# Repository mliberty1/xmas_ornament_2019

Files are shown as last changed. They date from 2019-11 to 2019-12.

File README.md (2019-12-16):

# Introduction

This repository contains the hardware and software for the ornament designed
for Christmas 2019.  The ornament contains LEDs that illuminate through the
circuit board.  The LEDs are controlled by a SAMD21 processor running Arduino
code.  The ornament looks like this:

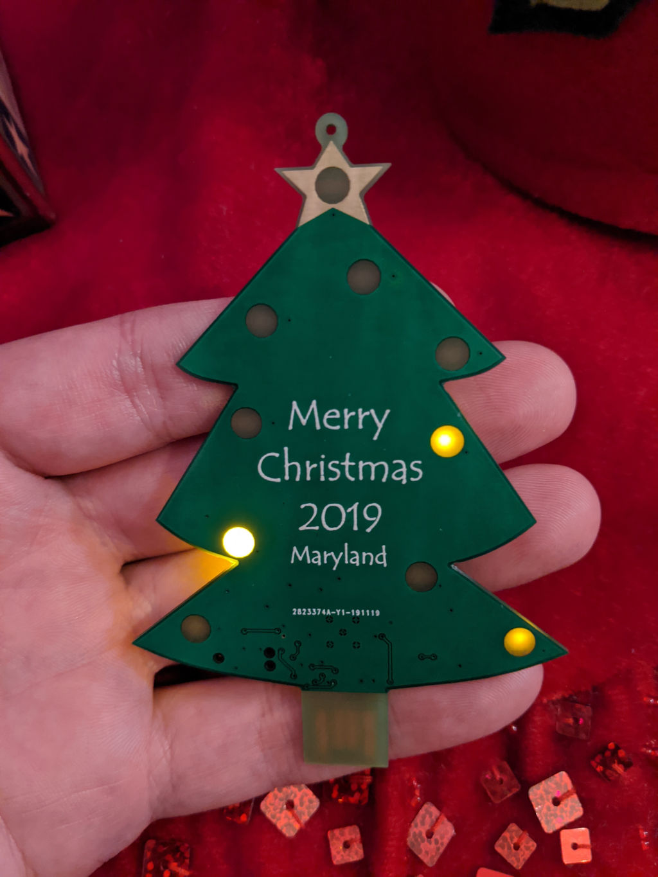
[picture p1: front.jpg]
front


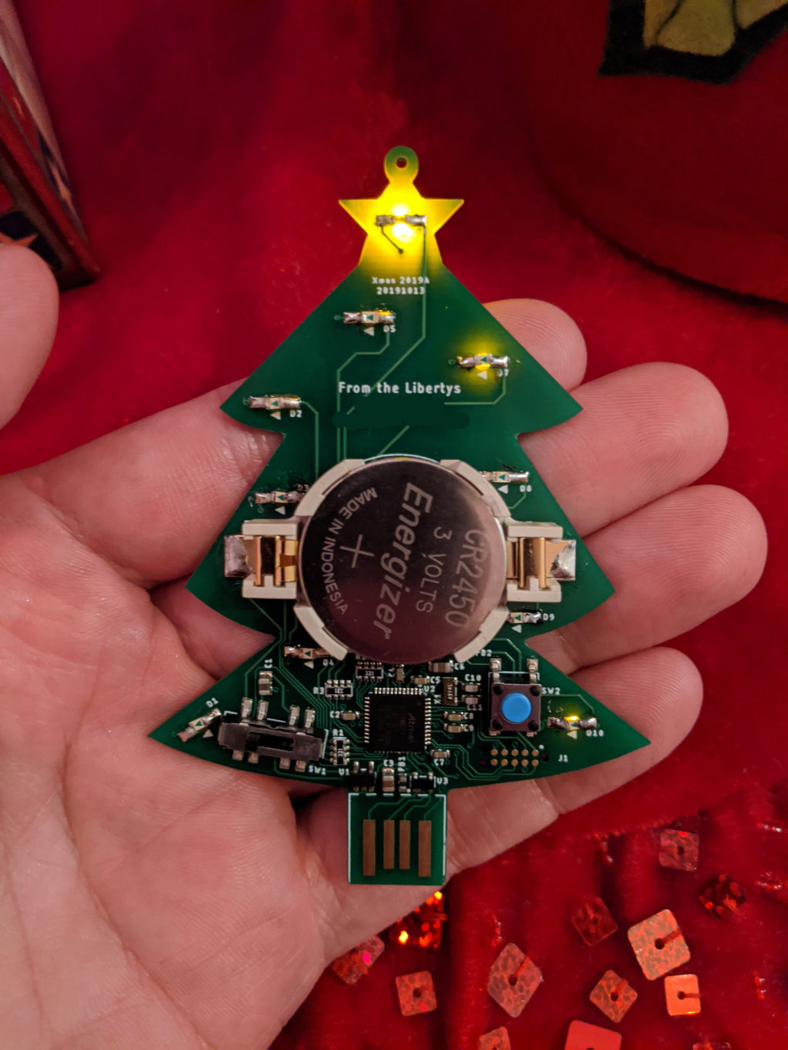
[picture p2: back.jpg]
back


# Configuration

This project is based upon the Arduino Zero, specifically the [Adafruit
Feather M0 Basic](https://learn.adafruit.com/adafruit-feather-m0-basic-proto/using-with-arduino-ide)
with the Adafruit bootloader.

https://adafruit.github.io/arduino-board-index/package_adafruit_index.json

Add Arduino SAMD21 boards.

Unfortunately, I used pins that did not normally have PWM (analogWrite) 
support.  So, I hacked the board variant definition so that it does.  For now,
you can replace the Feather M0 Express definition:

    cp arduino\variant.cpp "%LOCALAPPDATA%\Arduino15\packages\adafruit\hardware\samd\1.5.7\variants\feather_m0_express\variant.cpp"

## Manufacturing

* Surface mount all parts except LEDs and battery holder.
* Manually solder LEDs facing "wrong way".
* Manually solder battery holder.
* Program the [bootloader](https://learn.adafruit.com/how-to-program-samd-bootloaders).
* Program the Arduino program.

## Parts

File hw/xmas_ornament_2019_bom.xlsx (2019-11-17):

xmas_ornament_2019 rev A BOM
2019 November 17
# | Ref Des | Qty | Value | Package | Description | Mfg | Mfg Part # | Notes
1 | R1, R2, R3 | 3 | 330 | 4_1206 | 5%,200 ppm/°C,0.062W | Panasonic | EXB-38V331JV
2 | C10, C11 | 2 | 18p | 0603 | 5%,C0G,50V | Murata | GRM1885C1H180JA01D
3 | C2, C4, C7, C8 | 4 | 100n | 0603 | 20%,X5R,50V | Yageo | CC0603KRX7R9BB104
4 | C5, C9 | 2 | 1µ | 0603 | 20%,X5R,10V | Yageo | CC0603KRX5R6BB105
5 | C1, C3, C6 | 3 | 10µ | 0805 | 20%,X7R,6.3V | Taiyo Yuden | JMK212AB7106KGHT
6 | FB1, FB2 | 2 |  | 0603 |  | Wurth | 742792663
7 | D1, D2, D3, D4, D5, D6, D7, D8, D9, D10 | 10 |  | 0805 |  | Kingbright | APT2012LSYCK/J3-PRV
8 | X1 | 1 |  | 3.2x1.5mm |  | Epson | FC-135 32.7680KA-A5
9 | U3 | 1 |  | TO-253-4 |  | Nexperia | PRTR5V0U2X,215
10 | U2 | 1 |  | QFN-48 |  | Microchip | ATSAMD21G18A-MUT
11 | U1 | 1 |  | SOT-23-5 |  | TI | TLV75533PDBVR
12 | J2 | 1 |  |  |  | MPD | BU2450-SM-JJ-GTR
13 | SW2 | 1 |  |  |  | C&K | PTS645SM43SMTR92 LFS
14 | SW1 | 1 |  |  |  | C&K | JS203011SCQN
 |  | 33

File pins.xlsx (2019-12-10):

LED | Arduino | SAMD21 | E | F
D7 | 0 | PA10 | 1,0 | 0,2 | NOT_ON_PWM | NOT_ON_TIMER | TCC1_CH0
D8 | 1 | PA11 | 1,1 | 0,3 | NOT_ON_PWM | NOT_ON_TIMER | TCC1_CH1
D6 | 2 | PA14 | 3,0 | 0,4 | NOT_ON_PWM | NOT_ON_TIMER | TCC0_CH4
D9 | 3 | PA09 | 0,1 | 1,3 | PWM0_CH1 | TCC0_CH1
D10 | 4 | PA08 | 0,0 | 1,2 | PWM0_CH0 | TCC0_CH0
D5 | 5 | PA15 | 3,1 | 0,4 | PWM3_CH1 | TC3_CH1
 | 6 | PA20 | 7,0 | 0,6 | PWM0_CH6 | TCC0_CH6
 | 7 | PA21 | 7,1 | 0,7 | NOT_ON_PWM | NOT_ON_TIMER
 | 8 | PA6 | 1,0 | 3,4 | PWM1_CH0 | TCC1_CH0
 | 9 | PA7 | 1,1 | 3,5 | PWM1_CH1 | TCC1_CH1
D3 | 10 | PA18 | 3,0 | 0,2 | PWM3_CH0 | TC3_CH0
D4 | 11 | PA16 | 2,0 | 0,6 | PWM2_CH0 | TCC2_CH0
D1 | 12 | PA19 | 3,1 | 0,3 | PWM0_CH3 | TCC0_CH3
D2 | 13 | PA17 | 2,1 | 0,7 | PWM2_CH1 | TCC2_CH1

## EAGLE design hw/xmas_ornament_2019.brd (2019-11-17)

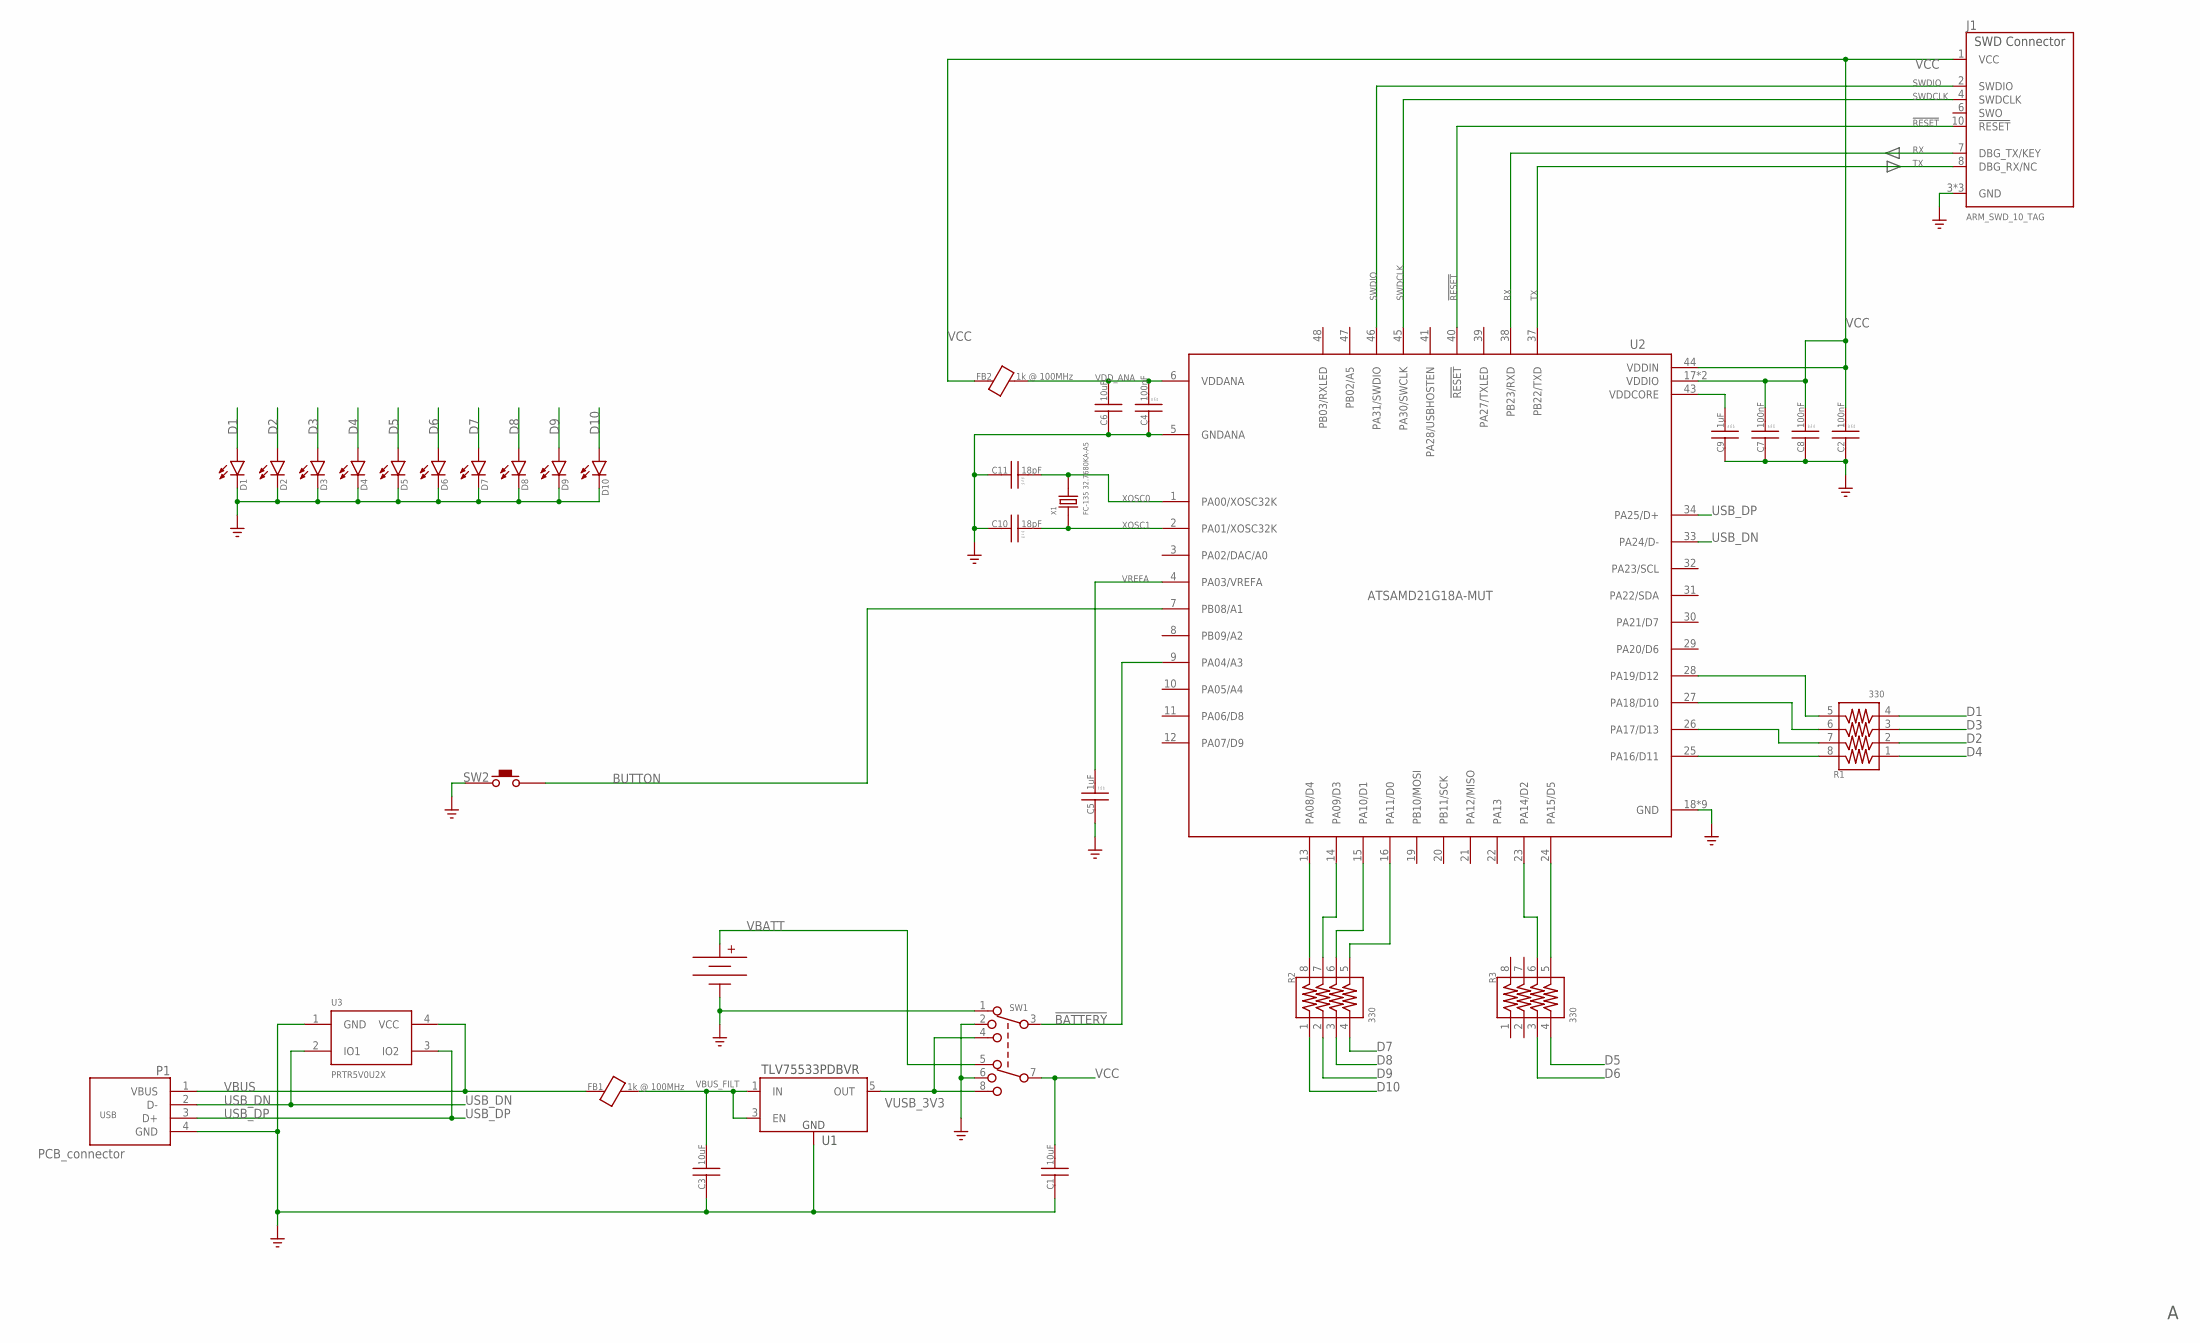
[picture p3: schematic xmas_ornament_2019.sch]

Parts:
C1, C3, C6: 10uF; 0805; TOLERANCE 20%; VOLTAGE 6.3V; MPN JMK212AB7106KGHT
C2, C4, C7, C8: 100nF; 0603; TOLERANCE 20%; VOLTAGE 50V; MPN CC0603KRX7R9BB104
C5, C9: 1uF; 0603; TOLERANCE 20%; VOLTAGE 10V; MPN CC0603KRX5R6BB105
C10, C11: 18pF; 0603; TOLERANCE 5%; VOLTAGE 50V; MPN GRM1885C1H220JA01D
D1, D2, D3, D4, D5, D6, D7, D8, D9, D10: APT2012LSYCK/J3-PRV; LED_0805_BREV; MPN APT2012LSYCK/J3-PRV
FB1, FB2: 1k @ 100MHz; 0603; MPN 742792663
J1: ARM_SWD_10_TAG; TC2050-IDC-NL
J2: BU2450-SM-JJ-GTR; BU2450SM-JJ-GTR; MPN BU2450-SM-JJ-GTR
P1: PCB_connector; USB-A_PCB
R1, R2, R3: 330; 1206X4; TOLERANCE 5%; MPN EXB-38V331JV
SW1: JS203011SCQN; MPN JS203011SCQN
SW2: PTS645SM43SMTR92 LFS; SWITCH_6MM; MPN PTS645SM43SMTR92 LFS
U1: TLV75533PDBVR; SOT23-5; MPN TLV75533PDBVR
U2: ATSAMD21G18A-MUT; QFN-48_GND
U3: PRTR5V0U2X; SOT143B; MPN PRTR5V0U2X,215
X1: FC-135 32.7680KA-A5; XTAL_3.2X1.5

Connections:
!BATTERY: SW1.3 (A_COM), U2.9 (PA04/A3)
!RESET: J1.10 (!RESET), U2.40 (!RESET)
BUTTON: SW2.1, SW2.2, U2.7 (PB08/A1)
D1: D1.A, R1.4 (4A)
D2: D2.A, R1.2 (2A)
D3: D3.A, R1.3 (3A)
D4: D4.A, R1.1 (1A)
D5: D5.A, R3.4 (4A)
D6: D6.A, R3.3 (3A)
D7: D7.A, R2.4 (4A)
D8: D8.A, R2.3 (3A)
D9: D9.A, R2.2 (2A)
D10: D10.A, R2.1 (1A)
GND: C1.1, C2.1, C3.1, C4.1, C5.1, C6.1, C7.1, C8.1, C9.1, C10.1, C11.1, D1.C, D2.C, D3.C, D4.C, D5.C, D6.C, D7.C, D8.C, D9.C, D10.C, J1.3 (GND), J1.5 (GND), J1.9 (GND), J2.-, P1.4 (GND), SW1.1 (A1), SW1.2 (A2), SW1.6 (B2), SW2.3, SW2.4, U1.2 (GND), U2.5 (GNDANA), U2.18 (GND), U2.35 (GND), U2.42 (GND), U2.GND, U2.GND@A (GND), U2.GND@A1 (GND), U2.GND@A2 (GND), U2.GND@A3 (GND), U2.GND@A4 (GND), U3.1 (GND)
unnamed: R2.8 (1B), U2.13 (PA08/D4)
unnamed: R2.7 (2B), U2.14 (PA09/D3)
unnamed: R2.6 (3B), U2.15 (PA10/D1)
unnamed: C9.2, U2.43 (VDDCORE)
unnamed: R2.5 (4B), U2.16 (PA11/D0)
unnamed: R1.8 (1B), U2.25 (PA16/D11)
unnamed: R1.7 (2B), U2.26 (PA17/D13)
unnamed: R1.5 (4B), U2.28 (PA19/D12)
unnamed: R1.6 (3B), U2.27 (PA18/D10)
unnamed: R3.5 (4B), U2.24 (PA15/D5)
unnamed: R3.6 (3B), U2.23 (PA14/D2)
RX: J1.7 (DBG_TX/KEY), U2.38 (PB23/RXD)
SWDCLK: J1.4 (SWDCLK), U2.45 (PA30/SWCLK)
SWDIO: J1.2 (SWDIO), U2.46 (PA31/SWDIO)
TX: J1.8 (DBG_RX/NC), U2.37 (PB22/TXD)
USB_DN: P1.2 (D-), U2.33 (PA24/D-), U3.2 (IO1)
USB_DP: P1.3 (D+), U2.34 (PA25/D+), U3.3 (IO2)
VBATT: J2.+, SW1.5 (B1)
VBUS: FB1.1, P1.1 (VBUS), U3.4 (VCC)
VBUS_FILT: C3.2, FB1.2, U1.1 (IN), U1.3 (EN)
VCC: C1.2, C2.2, C7.2, C8.2, FB2.1, J1.1 (VCC), SW1.7 (B_COM), U2.17 (VDDIO), U2.36 (VDDIO), U2.44 (VDDIN)
VDD_ANA: C4.2, C6.2, FB2.2, U2.6 (VDDANA)
VREFA: C5.2, U2.4 (PA03/VREFA)
VUSB_3V3: SW1.4 (A3), SW1.8 (B3), U1.5 (OUT)
XOSC0: C11.2, U2.1 (PA00/XOSC32K), X1.2
XOSC1: C10.2, U2.2 (PA01/XOSC32K), X1.1

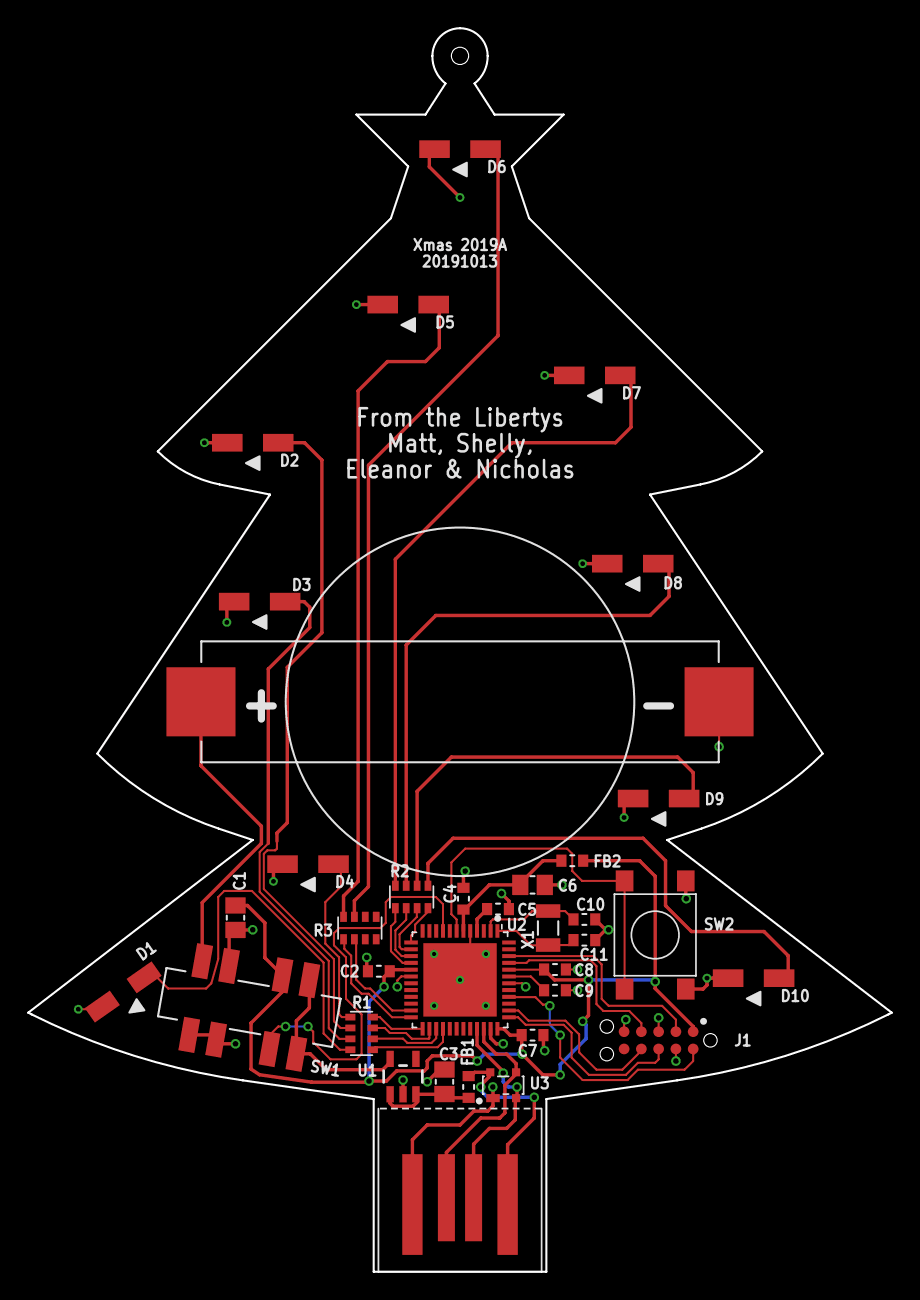
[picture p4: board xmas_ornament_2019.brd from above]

Board: 2 copper layers, 63.5 x 91.4 mm, 35 parts (0 on the bottom side), 40 nets.

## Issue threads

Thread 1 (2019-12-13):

PWM glitch on LED fade lower intensity

mliberty1, 2019-12-13:
When fading from a brighter LED intensity to a dimmer LED intensity, the LED brightness infrequently glitches to a brighter value.

The behavior could be caused by invalid updates by analogWrite of the TC peripherals.  The TCC peripherals support double buffering so that CCx registers are only updated at the rolloever from the CCBx registers.  The TC peripherals do not have this feature.  If CC_old > count > CC_new, then the match will not be triggered when CC is written with CC_new.  Therefore, the PWM output will remain active through the current cycle.  I suspect that the analogWrite driver does not have any mitigations.  One possible solution is to wait for the match to happen and then change the CC value.

mliberty1, 2019-12-13:
Code is in:
"%LOCALAPPDATA%\Arduino15\packages\arduino\hardware\samd\1.8.4\cores\arduino\wiring_analog.c"

See line 293:

```
        Tc* TCx = (Tc*) GetTC(pinDesc.ulPWMChannel);
        TCx->COUNT16.CC[tcChannel].reg = (uint32_t) value;
        syncTC_16(TCx);
```

Confirmed that the Arduino code performs no extra software handling to prevent glitches.

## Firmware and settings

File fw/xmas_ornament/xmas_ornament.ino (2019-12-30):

/* 
 * Liberty family Christmas ornament 2019
 * Arduino software for the SAMD21 (like Adafruit Feather M0 basic)
 */

/*
Instructions:

You can animate each LED using the asychronous commands:
   * led_set: set the LED intensity.
   * led_fade: smoothly transition from current intensity to a new intensity
   * led_delay: wait at the current intensity
   * led_signal: signal a function, which can program more commands.

The animation for each LED runs in parallel and independently.
However, you can chain together animations using the signal
callback.
*/

//https://github.com/adafruit/Adafruit_ZeroTimer/
// https://www.avdweb.nl/arduino/adc-dac/samd21-pwm-dac

#include "led.h"
#include "button.h"
#include <ArduinoLowPower.h>

#define PIN_BATTERY_N A3
const uint8_t leds[LED_COUNT] = {LED_10, LED_09, LED_08, LED_07, LED_06, LED_05, LED_02, LED_03, LED_04, LED_01};
const int ANIMATE_RANDOM_DURATION_MS = 500;
const int ANIMATE_SEQUENTIAL_DURATION_MS = 300;
const int ANIMATE_DAD_MS = 500;
const int ALTERNATE_FADE_MS = 500;
const int ALTERNATE_ON_MS = 500;
const int RUN_DURATION_MINUTES = 20;  // ~20 mA, ~620 mAh
const int RUN_DURATION_MS = RUN_DURATION_MINUTES * 60000;

int mode = 0;
int state = 0;
int time_start = 0;

void mode_set_all(void * user_data) {
  leds_write_all((int) user_data);
}

void mode_animate_down(void * user_data) {
  int led1 = 3 - state;
  int led2 = 6 + state;
  led_fade(led1, 255, ANIMATE_SEQUENTIAL_DURATION_MS);
  led_signal(led1, mode_animate_down, 0);
  led_delay(led1, ANIMATE_SEQUENTIAL_DURATION_MS);
  led_fade(led1, 0, ANIMATE_SEQUENTIAL_DURATION_MS);
  led_fade(led2, 255, ANIMATE_SEQUENTIAL_DURATION_MS);
  led_delay(led2, ANIMATE_SEQUENTIAL_DURATION_MS);
  led_fade(led2, 0, ANIMATE_SEQUENTIAL_DURATION_MS);
  ++state;
  if (state >= 4) {
    state = 0;
  }
  led_fade(4, 191 + random(64), ANIMATE_SEQUENTIAL_DURATION_MS);
}

void mode_down_alternate(void * user_data) {
  int led;
  if (state & 1) {
    led = 3 - (state >> 1);
  } else {
    led = 5 + (state >> 1);
  }
  led_fade(led, 255, ANIMATE_SEQUENTIAL_DURATION_MS);
  led_signal(led, mode_down_alternate, 0);
  led_delay(led, ANIMATE_SEQUENTIAL_DURATION_MS);
  led_fade(led, 0, ANIMATE_SEQUENTIAL_DURATION_MS);
  
  ++state;
  if (state > 8) {
    state = 0;
  }
  led_fade(4, 191 + random(64), ANIMATE_SEQUENTIAL_DURATION_MS);
}

void mode_animate_sequential(void * user_data) {
  int led = state;
  led_fade(led, 255, ANIMATE_SEQUENTIAL_DURATION_MS);
  led_signal(led, mode_animate_sequential, 0);
  led_delay(led, ANIMATE_SEQUENTIAL_DURATION_MS);
  led_fade(led, 0, ANIMATE_SEQUENTIAL_DURATION_MS);
  ++state;
  if (state >= LED_COUNT) {
    state = 0;
  }
}

void mode_gpa_fading(void * user_data) {
  for (int i = 0; i < 4; ++i) {
    for (int led = 0; led < LED_COUNT; ++led) {
      led_fade(led, 255, 500);
      led_delay(led, 500);
      led_fade(led, 0, 500);
      led_delay(led, 100);
    }
  }
  led_delay(4, 500);
  led_signal(4, mode_gpa, 0);
}

void mode_gpa_twinkle_star(void * user_data) {
  for (int i = 0; i < 3000; i += 100) {
    led_fade(4, 128 + random(128), 100);
  }
  led_signal(4, mode_gpa_fading, 0);
}

void mode_gpa(void * user_data) {
  led_fade(0, 255, 0);
  led_fade(9, 255, 0);
  for (int i = 0; i < 8; ++i) {
    int led = i;
    if (0 == (led & 1)) {
      led = 8 - (led >> 1);
    } else {
      led = 1 + (led >> 1);
    }
    led_delay(led, ANIMATE_DAD_MS + i * ANIMATE_DAD_MS);
    led_fade(led, 255, 0);
  }
  led_delay(4, ANIMATE_DAD_MS);
  led_signal(4, mode_gpa_twinkle_star, 0);
}

void mode_star_random(void * user_data) {
  int led = 4;
  while (led == 4) {
    led = led_random_from_idle();
  }
  led_fade(4, 191 + random(64), ANIMATE_RANDOM_DURATION_MS);
  led_fade(led, 255, ANIMATE_RANDOM_DURATION_MS);
  led_signal(led, mode_star_random, 0);
  led_delay(led, ANIMATE_RANDOM_DURATION_MS);
  led_fade(led, 0, ANIMATE_RANDOM_DURATION_MS);
}

void mode_animate_sequential_seizure(void * user_data) {
  int led = state;
  led_fade(led, 255, 5);
  led_delay(led, 10);
  led_fade(led, 0, 0);
  led_signal(led, mode_animate_sequential_seizure, 0);
  ++state;
  if (state >= LED_COUNT) {
    state = 0;
  }
}

void mode_alternate(void * user_data) {
  for (int led = state; led < 10; led += 2) {
    led_fade(led, 255, ALTERNATE_FADE_MS);
    led_delay(led, ALTERNATE_ON_MS);
    if (led == state) {
      led_signal(led, mode_alternate, 0);
    }
    led_fade(led, 0, ALTERNATE_FADE_MS);
  }
  state = (state + 1) & 1;
}

void mode_wait_for_button(void * user_data) {
  mode = 0;
  on_sleep();
}

struct mode_s {
  void * user_data;
  callback_fn initialize;
  callback_fn process;
};

// Define the modes: each button press switches to the next mode.
// Modify this structure to add your mode!
struct mode_s modes[] = {
  {0, mode_star_random, led_animate},
  {0, mode_animate_sequential_seizure, led_animate},
  {0, mode_animate_sequential, led_animate},
  {0, mode_animate_down, led_animate},
  {0, mode_down_alternate, led_animate},
  {0, mode_alternate, led_animate},
  {0, mode_gpa, led_animate},
  {(void *) 0, mode_set_all, mode_wait_for_button}  // off
};

// ----------------------------------------------------------------
// Animation engine: do not modify code below
// ----------------------------------------------------------------

void on_sleep() {
  led_clear();
  leds_write_all(0);
  LowPower.sleep();
  state = 0;
  time_start = millis();
  modes[mode].initialize(modes[mode].user_data);  
}

void on_wakeup() {
}

void setup() {
  analogWriteResolution(ADC_BITS);
  led_initialize();

  Serial.begin(9600);
  Serial.println("\n\nLiberty christmas ornament 2019");
  for (int i = 0; i < ARRAY_SIZE(leds); ++i) {
    pinMode(leds[i], OUTPUT);
  }
  pinMode(BUTTON, INPUT_PULLUP);
  pinMode(POWER_USB, INPUT);
  if (digitalRead(POWER_USB)) {
    Serial.println("powered over USB");
  } else {
    Serial.println("powered by battery");
  }
  if (modes[mode].initialize) {
    modes[mode].initialize(modes[mode].user_data);
  }
  LowPower.attachInterruptWakeup(BUTTON, on_wakeup, FALLING);
  time_start = millis();
}

void loop() {
  int runtime_ms = millis() - time_start;
  if (button_debounce() && runtime_ms > 50) {
      Serial.println("button pressed");
      led_clear();
      ++mode;
      time_start = millis();
      if (mode >= ARRAY_SIZE(modes)) {
        mode = 0;
      }
      if (modes[mode].initialize) {
        state = 0;
        modes[mode].initialize(modes[mode].user_data);
      }
  }

  if (modes[mode].process) {
    modes[mode].process(modes[mode].user_data);
  }

  if (!digitalRead(POWER_USB) && (runtime_ms > RUN_DURATION_MS)) {
    on_sleep();
  }
}

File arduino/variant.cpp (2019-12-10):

/*
  Copyright (c) 2014-2015 Arduino LLC.  All right reserved.

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
  You should have received a copy of the GNU Lesser General Public
  License along with this library; if not, write to the Free Software
  Foundation, Inc., 51 Franklin St, Fifth Floor, Boston, MA  02110-1301  USA
*/


#include "variant.h"

/*
 * Pins descriptions
 */
const PinDescription g_APinDescription[]=
{
  // 0..13 - Digital pins
  // ----------------------
  // 0/1 - SERCOM/UART (Serial1)
  { PORTA, 11, PIO_SERCOM, (PIN_ATTR_DIGITAL|PIN_ATTR_PWM|PIN_ATTR_TIMER), No_ADC_Channel, PWM1_CH1, TCC1_CH1, EXTERNAL_INT_11 }, // RX: SERCOM0/PAD[3]
  { PORTA, 10, PIO_SERCOM, (PIN_ATTR_DIGITAL|PIN_ATTR_PWM|PIN_ATTR_TIMER), No_ADC_Channel, PWM1_CH0, TCC1_CH0, EXTERNAL_INT_10 }, // TX: SERCOM0/PAD[2]

  // 2..12
  // Digital Low
  { PORTA, 14, PIO_DIGITAL, (PIN_ATTR_DIGITAL|PIN_ATTR_PWM|PIN_ATTR_TIMER), No_ADC_Channel, PWM3_CH0, TC3_CH0, EXTERNAL_INT_14 },
  { PORTA,  9, PIO_TIMER, (PIN_ATTR_DIGITAL|PIN_ATTR_PWM|PIN_ATTR_TIMER), No_ADC_Channel, PWM0_CH1, TCC0_CH1, EXTERNAL_INT_9 }, // TCC0/WO[1]
  { PORTA,  8, PIO_TIMER, (PIN_ATTR_DIGITAL|PIN_ATTR_PWM|PIN_ATTR_TIMER), No_ADC_Channel, PWM0_CH0, TCC0_CH0, EXTERNAL_INT_NMI },  // TCC0/WO[0]
  { PORTA, 15, PIO_TIMER, (PIN_ATTR_DIGITAL|PIN_ATTR_PWM|PIN_ATTR_TIMER), No_ADC_Channel, PWM3_CH1, TC3_CH1, EXTERNAL_INT_15 }, // TC3/WO[1]
  { PORTA, 20, PIO_TIMER_ALT, (PIN_ATTR_DIGITAL), No_ADC_Channel, NOT_ON_PWM, NOT_ON_TIMER, EXTERNAL_INT_4 }, // TCC0/WO[6]
  { PORTA, 21, PIO_DIGITAL, (PIN_ATTR_DIGITAL), No_ADC_Channel, NOT_ON_PWM, NOT_ON_TIMER, EXTERNAL_INT_5 },

  // Digital High
  { PORTA,  6, PIO_TIMER, (PIN_ATTR_DIGITAL), ADC_Channel6, NOT_ON_PWM, NOT_ON_TIMER, EXTERNAL_INT_6 }, // TCC1/WO[0]
  { PORTA,  7, PIO_TIMER, (PIN_ATTR_DIGITAL), ADC_Channel7, NOT_ON_PWM, NOT_ON_TIMER, EXTERNAL_INT_7 }, // TCC1/WO[1]
  { PORTA, 18, PIO_TIMER, (PIN_ATTR_DIGITAL|PIN_ATTR_PWM|PIN_ATTR_TIMER_ALT), No_ADC_Channel, PWM0_CH2, TCC0_CH2, EXTERNAL_INT_2 }, // TC3/WO[0]
  { PORTA, 16, PIO_TIMER, (PIN_ATTR_DIGITAL|PIN_ATTR_PWM|PIN_ATTR_TIMER), No_ADC_Channel, PWM2_CH0, TCC2_CH0, EXTERNAL_INT_0 }, // TCC2/WO[0]
  { PORTA, 19, PIO_TIMER_ALT, (PIN_ATTR_DIGITAL|PIN_ATTR_PWM|PIN_ATTR_TIMER_ALT), No_ADC_Channel, PWM0_CH3, TCC0_CH3, EXTERNAL_INT_3 }, // TCC0/WO[3]

  // 13 (LED)
  { PORTA, 17, PIO_PWM, (PIN_ATTR_DIGITAL|PIN_ATTR_PWM|PIN_ATTR_TIMER), No_ADC_Channel, PWM2_CH1, TCC2_CH1, EXTERNAL_INT_1 }, // TCC2/WO[1]

  // 14..19 - Analog pins
  // --------------------
  { PORTA,  2, PIO_ANALOG, PIN_ATTR_ANALOG, ADC_Channel0, NOT_ON_PWM, NOT_ON_TIMER, EXTERNAL_INT_2 }, // ADC/AIN[0]
  { PORTB,  8, PIO_ANALOG, 0, ADC_Channel2, NOT_ON_PWM, NOT_ON_TIMER, EXTERNAL_INT_8 }, // ADC/AIN[2]
  { PORTB,  9, PIO_ANALOG, 0, ADC_Channel3, NOT_ON_PWM, NOT_ON_TIMER, EXTERNAL_INT_9 }, // ADC/AIN[3]
  { PORTA,  4, PIO_ANALOG, 0, ADC_Channel4, NOT_ON_PWM, NOT_ON_TIMER, EXTERNAL_INT_4 }, // ADC/AIN[4]
  { PORTA,  5, PIO_ANALOG, 0, ADC_Channel5, NOT_ON_PWM, NOT_ON_TIMER, EXTERNAL_INT_5 }, // ADC/AIN[5]
  { PORTB,  2, PIO_ANALOG, 0, ADC_Channel10, NOT_ON_PWM, NOT_ON_TIMER, EXTERNAL_INT_2 }, // ADC/AIN[10]


  // Extra Analog pins! 20..25
  { PORTA,  6, PIO_ANALOG, (PIN_ATTR_DIGITAL|PIN_ATTR_ANALOG), ADC_Channel6, NOT_ON_PWM, NOT_ON_TIMER, EXTERNAL_INT_6 }, // A6 same as D8
  { PORTA,  7, PIO_ANALOG, (PIN_ATTR_DIGITAL|PIN_ATTR_ANALOG), ADC_Channel7, NOT_ON_PWM, NOT_ON_TIMER, EXTERNAL_INT_7 }, // A7 same as D9
  { PORTA,  8, PIO_ANALOG, (PIN_ATTR_DIGITAL|PIN_ATTR_ANALOG), ADC_Channel16, NOT_ON_PWM, NOT_ON_TIMER, EXTERNAL_INT_NMI },  // A8 same as D4
  { PORTA,  9, PIO_ANALOG, (PIN_ATTR_DIGITAL|PIN_ATTR_ANALOG), ADC_Channel17, NOT_ON_PWM, NOT_ON_TIMER, EXTERNAL_INT_9 },    // A9 same as D5
  { PORTA, 11, PIO_ANALOG, (PIN_ATTR_DIGITAL|PIN_ATTR_ANALOG), ADC_Channel19, NOT_ON_PWM, NOT_ON_TIMER, EXTERNAL_INT_11 }, // A10 same as D0
  { PORTA, 10, PIO_ANALOG, (PIN_ATTR_DIGITAL|PIN_ATTR_ANALOG), ADC_Channel18, NOT_ON_PWM, NOT_ON_TIMER, EXTERNAL_INT_10 }, // A11 same as D1

  // 26..27 I2C pins (SDA/SCL)
  // ----------------------
  { PORTA, 22, PIO_SERCOM, PIN_ATTR_DIGITAL, No_ADC_Channel, NOT_ON_PWM, NOT_ON_TIMER, EXTERNAL_INT_6 }, // SDA: SERCOM3/PAD[0]
  { PORTA, 23, PIO_SERCOM, PIN_ATTR_DIGITAL, No_ADC_Channel, NOT_ON_PWM, NOT_ON_TIMER, EXTERNAL_INT_7 }, // SCL: SERCOM3/PAD[1]

  // 28..30 - SPI pins (ICSP:MISO,SCK,MOSI)
  // ----------------------
  { PORTA, 12, PIO_SERCOM_ALT, PIN_ATTR_DIGITAL, No_ADC_Channel, NOT_ON_PWM, NOT_ON_TIMER, EXTERNAL_INT_12 }, // MISO: SERCOM4/PAD[0]
  { PORTB, 10, PIO_SERCOM_ALT, PIN_ATTR_DIGITAL, No_ADC_Channel, NOT_ON_PWM, NOT_ON_TIMER, EXTERNAL_INT_10 }, // MOSI: SERCOM4/PAD[2]
  { PORTB, 11, PIO_SERCOM_ALT, PIN_ATTR_DIGITAL, No_ADC_Channel, NOT_ON_PWM, NOT_ON_TIMER, EXTERNAL_INT_11 }, // SCK: SERCOM4/PAD[3]

  // 31..32 - RX/TX LEDS (PB03/PA27)  -- unused
  // --------------------
  { PORTB,  3, PIO_OUTPUT, PIN_ATTR_DIGITAL, No_ADC_Channel, NOT_ON_PWM, NOT_ON_TIMER, EXTERNAL_INT_NONE }, // used as output only
  { PORTA, 27, PIO_OUTPUT, PIN_ATTR_DIGITAL, No_ADC_Channel, NOT_ON_PWM, NOT_ON_TIMER, EXTERNAL_INT_NONE }, // used as output only

  // 33..35 - USB
  // --------------------
  { PORTA, 28, PIO_COM, PIN_ATTR_NONE, No_ADC_Channel, NOT_ON_PWM, NOT_ON_TIMER, EXTERNAL_INT_NONE }, // USB Host enable
  { PORTA, 24, PIO_COM, PIN_ATTR_NONE, No_ADC_Channel, NOT_ON_PWM, NOT_ON_TIMER, EXTERNAL_INT_NONE }, // USB/DM
  { PORTA, 25, PIO_COM, PIN_ATTR_NONE, No_ADC_Channel, NOT_ON_PWM, NOT_ON_TIMER, EXTERNAL_INT_NONE }, // USB/DP

  // 36..38 - Secondary SPI
  // ----------------------
  { PORTA, 14, PIO_SERCOM,     (PIN_ATTR_DIGITAL), No_ADC_Channel, NOT_ON_PWM, NOT_ON_TIMER, EXTERNAL_INT_NONE },  // SPI Flash MISO SERCOM2.2
  { PORTA,  8, PIO_SERCOM_ALT, (PIN_ATTR_DIGITAL), No_ADC_Channel, NOT_ON_PWM, NOT_ON_TIMER, EXTERNAL_INT_NONE },  // SPI Flash MOSI SERCOM2.0
  { PORTA,  9, PIO_SERCOM_ALT, (PIN_ATTR_DIGITAL), No_ADC_Channel, NOT_ON_PWM, NOT_ON_TIMER, EXTERNAL_INT_NONE },  // SPI Flash SCK  SERCOM2.1

  // 39 Secondary SPI SS
  { PORTA, 13, PIO_DIGITAL, PIN_ATTR_DIGITAL, No_ADC_Channel, NOT_ON_PWM, NOT_ON_TIMER, EXTERNAL_INT_13 }, // SPI Flash SS

  // 40 same as #8 - Internal NeoPixel (to match Metro M0)
  { PORTA,  6, PIO_TIMER, (PIN_ATTR_DIGITAL|PIN_ATTR_ANALOG), ADC_Channel6, NOT_ON_PWM, NOT_ON_TIMER, EXTERNAL_INT_6 }, // TCC1/WO[0]

  // 41 (AREF)
  { PORTA, 3, PIO_ANALOG, PIN_ATTR_ANALOG, No_ADC_Channel, NOT_ON_PWM, NOT_ON_TIMER, EXTERNAL_INT_NONE }, // DAC/VREFP

  // ----------------------
  // 42 - Alternate use of A0 (DAC output)
  { PORTA,  2, PIO_ANALOG, PIN_ATTR_ANALOG, DAC_Channel0, NOT_ON_PWM, NOT_ON_TIMER, EXTERNAL_INT_2 }, // DAC/VOUT
} ;

const void* g_apTCInstances[TCC_INST_NUM+TC_INST_NUM]={ TCC0, TCC1, TCC2, TC3, TC4, TC5 } ;

// Multi-serial objects instantiation
SERCOM sercom0( SERCOM0 ) ;
SERCOM sercom1( SERCOM1 ) ;
SERCOM sercom2( SERCOM2 ) ;
SERCOM sercom3( SERCOM3 ) ;
SERCOM sercom4( SERCOM4 ) ;
SERCOM sercom5( SERCOM5 ) ;
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

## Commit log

2019-10-27 Board in progress.
    [xmas_ornament_2019.brd, xmas_ornament_2019.sch]
2019-11-16 Current progress.
    [xmas_ornament_2019.brd, xmas_ornament_2019.sch]
2019-11-16 Added artwork
    [xmas_ornament_2019.brd, xmas_ornament_2019.sch]
2019-11-17 Rev A.
    [xmas_ornament_2019.brd, xmas_ornament_2019.sch, xmas_ornament_2019_bom.xlsx]
2019-12-10 Added initial Arduino sketch.
    [pins.xlsx]
2019-12-10 Analog PWM working.
    [pins.xlsx]
2019-12-11 Added led_delay_random
2019-12-11 Refactored button.
2019-12-11 Start next LED command immediately on done.
2019-12-16 Fixed fading to dimmer on TC using interrupts to implement software "double-buffer".
    [led.cpp, led.h]
2019-12-17 Added low-power sleep and additional blink patterns.
